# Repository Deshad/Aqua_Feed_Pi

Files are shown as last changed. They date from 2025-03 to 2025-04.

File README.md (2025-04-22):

# Aqua Matic  
# **Smart Aquarium Management System** 🐠
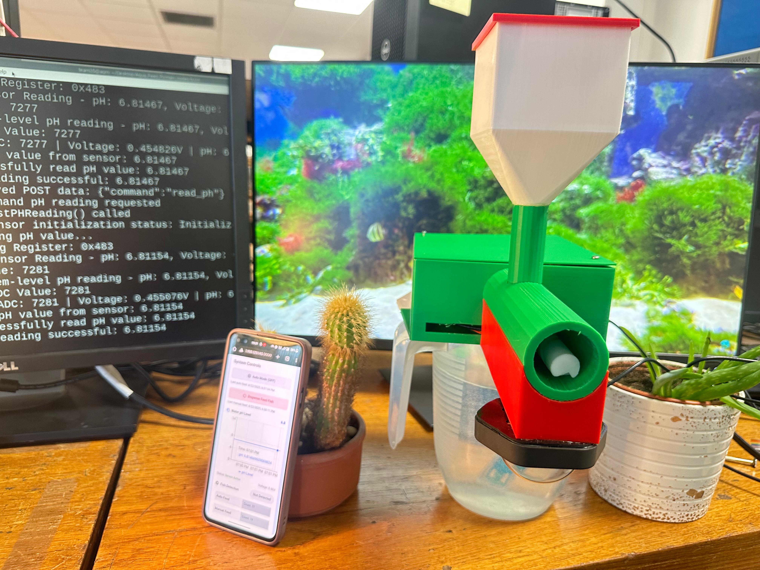
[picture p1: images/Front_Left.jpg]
 

## **📌 Project Overview**  
**Aqua Matic** is a smart, automated aquarium management system that uses a **PIR sensor and Pi-camera** to detect fish presence and regulate feeding schedules. 
For the people who love their goldies but can’t always be there—Aqua Feed Pi ensures your fish are fed, happy, and thriving, even when you're away! 🐠✨
Designed with Raspberry Pi, this project helps automate fish feeding efficiently, ensuring optimal care even when you're away.  

## **🚀 Features**  
✅ **Automated Feeding:** Dispenses food when fish are detected.  
✅ **PIR & Camera-based Detection:** Monitors fish activity for intelligent feeding.  
✅ **Remote Access:** Control and monitor the system via SSH or a web dashboard.

✅ **pH Monitoring:** Monitor pH value of the tank. 

✅ **Configurable Parameters:** Adjust feeding schedules and sensor sensitivity.  
✅ **Energy Efficient:** Optimized to reduce unnecessary food waste.  

---

## **🔧 System Components**  

- **Hardware:**  
  - Raspberry Pi  
  - PIR Motion Sensor  
  - Camera Module
  - pH Sensor    
  - DC Motor (for feeding mechanism)  
  - Power Supply  
  - Wi-Fi Module (optional, for remote access)
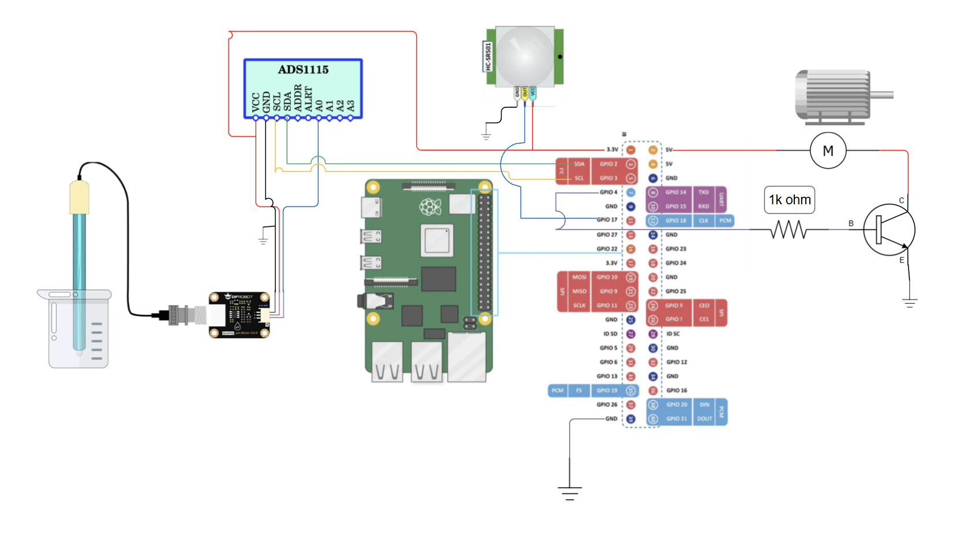
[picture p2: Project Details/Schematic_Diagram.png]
    

- **Software:**
  - OS (for Raspberry Pi system)
  - Cpp (for system control)  
  - OpenCV (for fish detection via camera)  
  - RPi.GPIO (for PIR and  motor control)  
  - Next.js (for web-based monitoring)  

---
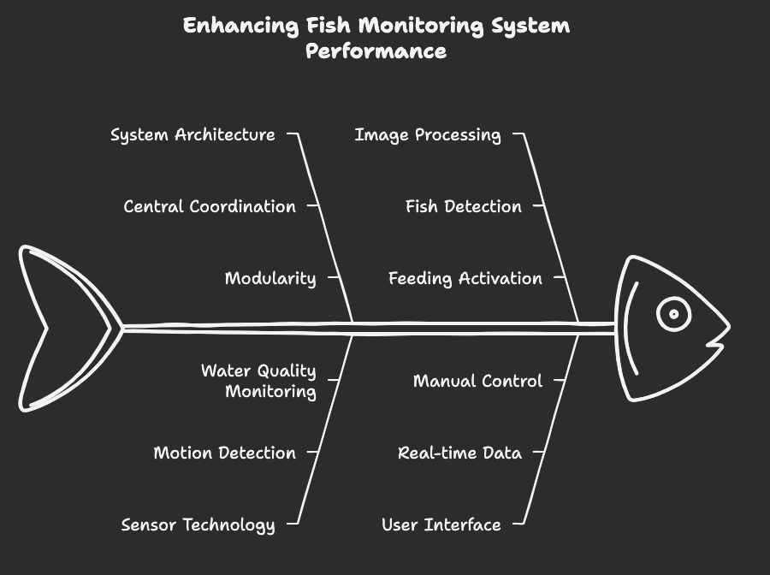
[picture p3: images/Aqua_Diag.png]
Aqua Matic Flow Chart
 

## **🛠 Installation & Setup**  

### **1️⃣ Clone the Repository**  
Make sure you have **Git** installed, then run:  

```bash
git clone https://github.com/Deshad/Aqua_Feed_Pi.git
cd Aqua_Feed_Pi

rm -rf build
mkdir build
cmake ..
make

```
Removing the build folder and make it again.

### **2️⃣ Install Dependencies**  
Install the following packages (on Debian-based systems):

```bash
sudo apt update
sudo apt install \
  libopencv-dev (>=4.5.0) \
  libjsoncpp-dev (>=1.9.4) \
  libgpiod-dev (>=1.6.0) \
  libi2c-dev \
  libcamera-dev \
  libcamera-tools
```
### **3️⃣ Setup Raspberry Pi Configuration**  

#### **Enable Camera**  

```bash
sudo raspi-config
```
- Navigate to *Interfacing Options* → *Enable Camera* → *Finish & Reboot*.  

#### **Enable PIR Sensor GPIO**  
Ensure you have connected the PIR sensor properly to the Raspberry Pi's GPIO pins.  

#### **Enable Motor GPIO**  
Ensure you have connected the transistor and motor properly to the Raspberry Pi's GPIO pins.  

#### **Enable I2C GPIO for PH Sensor**  
Ensure you have connected the ADC module (ADS1115) properly to the Raspberry Pi's GPIO pins 2 (SDA) & 3 (SCL).  
```bash
sudo raspi-config
```
- Navigate to *Interfacing Options* → *I2C* → *Yes* → *Finish & Reboot*.

(Install I2C Tools)
```bash
sudo apt install -y i2c-tools python3-smbus
```
---

## **🚀 Running the System**  

Execute the main script:  (file present in main_codes)

```bash
cd ~/Aqua_Feed_Pi/build
./fish_monitor
```
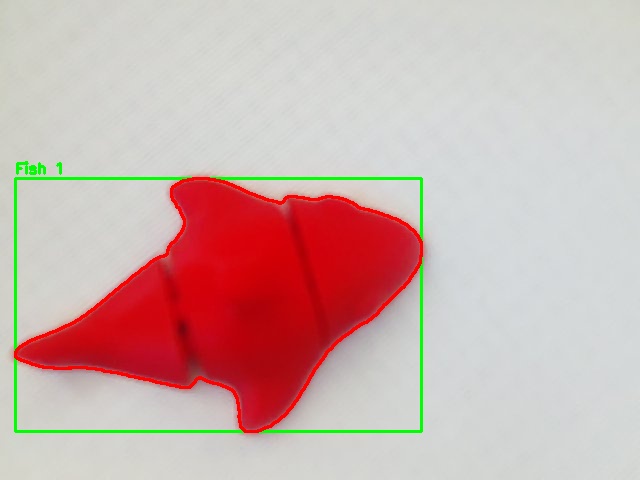
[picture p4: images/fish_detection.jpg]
 

---

## **🛠 Configuration**  

Modify `config.json` to adjust:  
- Feeding schedule  
- PIR sensor sensitivity  
- Camera threshold settings  

---

For web-based monitoring, run:  (file present in web folder)

```bash
npm run dev
```
Then, access the dashboard via your browser at `http://localhost:8000`.  

---

## **🐟 Troubleshooting**  

| Issue | Solution |
|---|---|
| Camera not detected | Run `vcgencmd get_camera` and check if `detected=1`. |
| PIR sensor not triggering | Check GPIO connections and ensure the correct pin mapping. |
| Motor not working | Ensure it’s connected properly and receiving the correct PWM signal. |
| PH Sensor incorrect measurement | Ensure the calibration of the PH level is correctly. |

---

## **🤝 Contributing**  

Contributions are welcome! If you’d like to improve the system, open an issue or submit a pull request.  

---

## **📜 License**  

This project is open-source under the MIT License.

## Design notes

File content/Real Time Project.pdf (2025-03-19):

AquaFeedPi

Objective:-
To predict when fish are hungry, you can monitor behavioral patterns or physiological changes. While it is challenging to determine when fish are hungry, they do not exhibit clear signs like other pets, such as dogs.
Usually, aquarium fish swim toward the surface because they associate the surface with food due to positive reinforcement, especially domesticated fish.

Theory:-
The lack of clear cues presents a challenging aspect of this project.
We can divide the indicators into two categories: Environmental and Behavioral.
1. Environmental Indicators:-Changes in water conditions can indirectly indicate hunger or feeding requirements.
a) pH Levels: (Possible)
The decomposition of uneaten food increases the alkalinity (pH) of water.
A sudden rise in pH may indicate that food is not being consumed, signaling potential hunger or overfeeding scenarios.
b) Dissolved Oxygen (DO) Levels: (Possible)
Well-fed fish are less active and consume less oxygen compared to hungry fish, which may exhibit increased swimming and oxygen consumption.
c) Nitrate/Nitrite Levels:(Sensor issue)
Low nitrate levels over time may imply that fish consume all provided food without leftovers, indicating efficient feeding and potential hunger at scheduled times.
2. Behavioral Patterns
Observing how fish behave under different feeding conditions can provide important insights:
a) Surface Activity:Hungry fish often swim near the water surface, eagerly waiting for food. Movement and Agitation:Increased erratic movements or gathering near feeding zones can indicate hunger.
b) Feeding Frenzy:A sudden rush to the feeding area when food is dropped may imply prior hunger.

Possible Solution:-
1.Infrared (IR) Motion Sensors:(Possible)
Detects increased activity near the feeding area (e.g., fish swimming near the surface). Example: HC-SR501 PIR Motion Sensor.
2.Underwater Cameras + Image Processing:
Use OpenCV or machine learning to analyze fish behavior (e.g., clustering near the feeder). 3.Water Quality Sensors:

Monitor parameters like dissolved oxygen or ammonia levels, which correlate with feeding activity.
Example: DFRobot Analog Dissolved Oxygen Sensor.
4.Ultrasonic Sensors:
Detect movement near the feeding zone (e.g., HC-SR04).
5.Load Cells:
Measure uneaten food to adjust feeding schedules (e.g., HX711 Load Cell). Usually used for dog feeder setups, so we have to see if it will be possible for fishes.

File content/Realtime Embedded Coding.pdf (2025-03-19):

# Realtime embedded coding in C++ under Linux

### Bernd Porr & Nick Bailey

### April 3, 2024

# Contents

1 Introduction | 3
2 Writing C++ device driver classes | 5
2.1 General recommendations on how to write your C++ classes for
2.2.2 | Adding directly an abstract method to the device driver
3 Threads | 19

1

### 4 Realtime/event processing within the Graphical User Interface

Qt | 24
5 Realtime web server/client communication | 28
6 Setters | 34
A License | 36

2

# Chapter 1

# Introduction

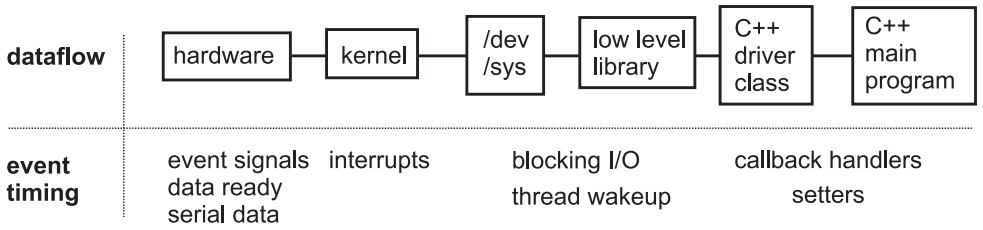
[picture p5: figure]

Figure 1.1: Dataflow and timing in low level realtime coding

## 1.1 Event based coding in the Linux userspace

Realtime embedded coding is all about events. These can be a binary signal such as somebody opening a door or an ADC signalling that a sample is ready to be picked up. Fig. 1.1 shows the basic dataflow and how event timing is established: devices by themselves have event signals such as “data ready” or “crash sensor has been triggered”. The Linux kernel receives these as interrupt callbacks. However, userspace has no direct interrupt mechanism; instead it has blocking I/O where a read or write operation blocks until a kernel-side interrupt has happened. A blocking I/O call returning may then be translated callbacks between classes by waking up threads. Data is transmitted back to the hardware via methods called “setters”, which change an object’s attributes and potentially do other processing.

3

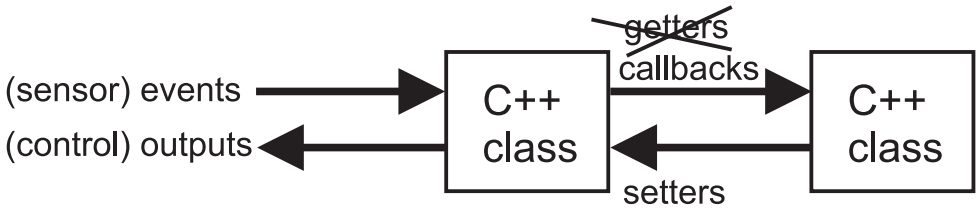
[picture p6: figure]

Figure 1.2: A realtime system with two C++ classes. Communication between classes is achieved with callbacks (not getters) for incoming events and setters to send out control events. The control output itself receives its timing from the events so that the loop is traversed as quickly as possible.

Fig. 1.2 shows the overall communication between C++ classes in a realtime system. This communication is done via callbacks (not getters) and setters, where an event from a sensor traverses according to its realtime requirements through the C++ classes via callbacks and then back to the control output via setters. For example, a collision sensor at a robot triggers a GPIO pin, which then triggers a callback to issue an avoidance action which in turn then sets the motors in reverse.
Callbacks can be seen as userspace interrupt service routines. These must always complete immediately so that the caller is not experience any noticeable delay. For example when a user presses a button in a GUI the callback must be processed without any noticeable delay which is application specific. If processing takes longer then a thread should be started which in turn then will then have a callback signalling success.
In the following sections we are describing how to write event driven code in C++. Important here is the interplay between blocking I/O and threads: chapter 2 focuses on how to wrap the low level blocking Linux I/O in a class and how to establish the communication between classes while the chapter 3 describes how threads can effectively be used to trigger callbacks with blocking I/O. Chapter 4 then presents the event based communication in Qt, in particular user interaction and animations. Chapter 5 tackles the same issues as for Qt but for website server communication. The final chapter 6 then describes how events are transmitted back from a C++ class to the user with the help of setters.

4

# Chapter 2

# Writing C++ device driver classes

This chapter focuses on writing your own C++ device driver class hiding away the complexity (and messy) low level C APIs and/or raw device access. How are events translated into I/O operations? On the hardware-side we have event signals such as data-ready signals or by the timing of a serial or audio interface. The Linux kernel translates this timing info into blocking I/O on the pseudo filesystem /dev which means that a read operation blocks until data has arrived or an event has happened. The task of a C++ programmer is to hide this complexity and these quite different approaches in C++ classes which communicate via callbacks and setters with the client classes. The rest of the program will then appear simple and be easy to maintain.

## 2.1 General recommendations on how to write your C++ classes for devices

As said above the main purpose of object oriented coding here is to hide away the complexity of low level driver access and offer the client a simple and safe way of connecting to the sensor. In particular:

1. Setters and callbacks hand over physical units (temperature, acceleration, . . . ) or relative units but not raw integer values with no meaning.
2. The sensor is configured by specifying physical units (time, voltage, temperature) and not sensor registers. Default config parameters should be specified that the class can be used straight away with default parameters.

5

3. The class comes with simple demo programs demonstrating how a client program might use it.

## 2.2 Callbacks in C++ device classes

As said in the introduction your hardware device class has callback interfaces to hand back the data to the client.
There are different ways of tackling the issue of callbacks but the simplest one is defining a method as abstract and asking the client to implement it in a derived class. That abstract function can either be in a separate interface class or part of the device class itself. So, we have two options:
1. The callback is part of the device driver class:

class MyDriver {
void start(DevSettings settings = DevSettings() ); void stop();
virtual void callback(float sample) = 0;
};
2. The callback is part of an interface class:

class CallbackInterface {
virtual void callback(float sample) = 0; };

and then registering it in the main device driver class:

class MyDriver {
void registerCallback(CallbackInterface* cb); };

These two options are now explained in greater detail.

6

### 2.2.1 Creating a callback interface

Here, we create a separate interface class containing a callback as an abstract method:

class LSM9DS1callback {
public:
virtual void hasSample(LSM9DS1Sample sample) = 0;
};

The client then implements the abstract method hasSample(), instantiates the interface class and then saves its pointer in the device class, here called lsm9ds1Callback.

void LSM9DS1::dataReady() {
LSM9DS1Sample sample;
// fills the sample struct with data // ...
lsm9ds1Callback->hasSample(sample); }

The pointer to the interface instance is transmitted via a setter which receives the pointer of the interface as an argument, for example:

void LSM9DS1::registerCallback(LSM9DS1callback* cb);

This allows to register a callback optionally. The client may or may not need one. See https://github.com/berndporr/rpi_AD7705_daq for a complete example.

### 2.2.2 Adding directly an abstract method to the device driver class

Instead of creating a separate class containing the callback you can also add the callback straight to the device driver class.

class ADS1115rpi {
virtual void hasSample(float sample) = 0; ...
};

7

This forces the client to implement the callback to be able to use the class. This creates a very safe environment as all dependencies are set at compile time and the abstract nature of the base class makes clear what needs to be implemented. See https://github.com/berndporr/rpi_ads1115 for a complete example.

### 2.2.3 Callback arguments

Above the callbacks just delivered one floating point value. However, often more than one sample or more complex data are transmitted:

- Complex data: do not put loads of arguments into the callback but define a struct. For example an ADC might deliver all 4 channels at once:

class ADmulti {

struct ADCSample {
float ch1;
float ch2;
float ch3;
float ch4;
};
virtual void hasSample(ADCSample sample) = 0; ...
};

Depending on your application, you might consider the values not useful individually and therefore prefer a std::tuple.

- Arrays: Use arrays which contain the length of the arrays: either std::array, std::vector, etc or const arrays and then references to these so that the callback knows the length. For example the LIDAR callback uses a reference to a const length array:

/**
* Callback interface which needs to be implemented by the user. **/
struct DataInterface {

8

virtual void newScanAvail( float rpm,
A1LidarData (&)[A1Lidar::nDistance]) = 0; };

Here A1Lidar::nDistance is a constant-expression giving the fixed array length, and (&)[A1Lidar::nDistance] a reference to a constant-length array which containing A1LidarData stucts. If you’re going to use types that hard to key-in often, typedef them.

In terms of memory management:

1. Low sampling rate complex data structures: allocate as a local variable. It
can be a simple type or a struct. See dataReady() in: https://github.com/berndporr/LSM9DS1_RaspberryPi_CPP_Library/blob/master/LSM9DS1. cpp. (https://github.com/berndporr/LSM9DS1_RaspberryPi_CPP_Library/blob/master/LSM9DS1.cpp)
2. High sampling rate buffers: allocate memory on the heap in the constructor
or in the private section of the class as a const length array and pass on a reference. See getData() in https://github.com/berndporr/rplidar_rpi. (https://github.com/berndporr/rplidar_rpi)

## 2.3 Low level userspace device access

The following sections provide pointers of how to write the C++ driver classes for different hardware protocols.
To emulate an “interrupt” or event in userspace we need blocking I/O which provides the timing for example when waiting for a GPIO change, doing audio or video I/O.
Generally any userspace program talks to the kernel via pseudo files in the /dev or /sys directories.

### 2.3.1 Video camera capture (openCV)

Ubuntu / Debian Linux systems

Reading from a video camera is usually done with the help of openCV which in turn then talks to the low level C API which in turn talks to the kernel via /dev/video*.

9

while(running) {
cv::Mat cap;
videoCapture.read(cap);
sceneCallback->nextScene(cap);
}

The read(cap) command is blocking till a new frame has arrived which is then transmitted with the callback nextScene to the client. The full code of the example camera class is here: https://github.com/berndporr/opencv-camera-callback.

Raspberry PI

On the raspberry PI a new video stack has been implemented which talks to the kernel via /dev/media*. This is incompatible with openCV and the code in section 2.3.1 won’t work. The good news is that libcamera already implements a callback interface so a loop is no longer needed. Instead, one just needs to
register a callback to receive the video frames. The bad news is that libcamera
is highly complex and requires a lot of additional code (https://github.com/libcamera-org/libcamera/blob/master/Documentation/guides/application-developer. rst). (https://github.com/libcamera-org/libcamera/blob/master/Documentation/guides/application-developer.rst) To make life easier we have written a C++ wrapper around the libcamera
C++ API which exposes a callback which delivers image frames in openCV format to mimick the behaviour of the openCV code of the previous section 2.3.1: https://github.com/berndporr/libcamera2opencv.

### 2.3.2 Audio (ALSA)

The standard framework for audio is alsa: https://github.com/alsa-project. ALSA is packet based with a read command returning a chunk (”buffer”) of audio and write emitting one. There are calls to set the sample format, sample rate, buffer size and so forth.
First, the parameters are requested and the driver can modify or reject them:

/* Signed 16-bit little-endian format */ snd_pcm_hw_params_set_format(handle, params, SND_PCM_FORMAT_S16_LE);

/* One channel (mono) */
snd_pcm_hw_params_set_channels(handle, params, 1);

10

/* 44100 bits/second sampling rate (CD quality) */ val = 44100;
snd_pcm_hw_params_set_rate_near(handle, params,
&val, &dir);

Then playing sound is done in an endless loop were a read() or write() command is issued. Both are blocking so that they guarantee event timing of audio both way.

while (running) {
if ((err = snd_pcm_readi (handle, buffer, buffer_frames)) != buffer_frames) { if (errCallback) errCallback->hasError();
}
if (sampleCallback) sampleCallback->hasData(buffer);
}

For a full coding example “aplay” and “arecord” are a good start. Both can be found here: https://github.com/alsa-project.

### 2.3.3 Bluetooth

Bluetooth has also blocking I/O so that one can wait for incoming packets on a socket:

void run() {
doRun = 1;
while (doRun) {
recv(btsocket, recvbuffer, sizeof(recvbuffer), 0); hasData(recvbuffer);
}
};

Here the recv command blocks until new data has arrived.

### 2.3.4 General purpose I/O (GPIO)

GPIO pins are not just simple digital ports but they can be used to turn non-blocking I/O into blocking I/O, or in other words: events!

11

libgpiod

The GPIO (of the raspberry PI) can easily be controlled via the /dev filesystem and libgpiod.
Use the commandline tool gpioinfo to print a list of all available GPIO pins. When you use the gpiod library you:
1. first choose the GPIO chip you want to use. Raspberry PIs 1-4 have only one chip. The Raspberry PI 5 has 4 chips. Selection can be made either by number, name or pseudo-file:

struct gpiod_chip *chip =
gpiod_chip_open_by_name("gpiochip0");

and then,

2. select a pin on the chip:

struct gpiod_line *pinRed = gpiod_chip_get_line(chip, 24);

Output

Once you have a pointer to the pin you can then set its direction, for example as an output pin, with:

gpiod_line_request_output(pinRed, "example1", 0);

and set its value with:

gpiod_line_set_value(pinRed, 1);

Events

Blocking I/O is very good for event processing. Calling a blocking I/O function causes the thread to wait efficiently, then when the I/O call returns, the thread will wake up. This means that a change in level from low to high or high to low unblocks an I/O operation, awakening its underlying thread which then performs a callback.
To request event processing on a pin simply requires this single command:

12

int ret =
gpiod_line_request_rising_edge_events(pinSwitch, "Consumer1");

This will turn the GPIO pin pinSwitch into an input pin and enable blocking I/O on this pin.
Then start a thread where its worker contains:

void worker() {
while (running) {
constexpr struct timespec ts = { 1, 0 }; gpiod_line_event_wait(pinSwitch, &ts); struct gpiod_line_event event; gpiod_line_event_read(pinSwitch, &event); event_callback();
}
}

The gpiod line event wait waits for a rising edge at the GPIO pin, or for 1 second (+ 0 ns), whichever is longer, and then unblocks. The return value is 1 if a GPIO event occurred, 0 if timeout interval was exceeded, and -1 in the event of an error. In production code, you’d need to check this return value. Then gpiod line event read transfers the kernel event to userspace and clears it out of the kernel event queue. It’s important to do the read operation even if the event-struct is never used. The callback is made, and the loop repeats until another thread requrests termination by setting running to false. See https://github.com/berndporr/rpi_ads1115 for a complete example.

Releasing the GPIO

Once you are finished, release the GPIO pin with:

gpiod_line_release(pinRed);

and close the chip:

gpiod_chip_close(chip);

13

Table 2.1: SPI modes

SPI Mode | CPOL | CPHA | Idle state
0 | 0 | 0 | L
1 | 0 | 1 | L
2 | 1 | 1 | H
3 | 1 | 0 | H

### 2.3.5 SPI

SPI is a protocol which usually transmits and receives at the same time. Its calls are blocking for the duration of receive and transmit but cannot be used for event based processing. If an SPI device is used events should be transmitted via an additional GPIO line. Even though data might not be used it needs to be matched up, because the same clock is used to send and collect the data signal (it is isochronous). So if you send 8 bytes the hardware receives 8 bytes at the same time.
Transfer to/from SPI is best managed by the low level access to /dev. Open the SPI device with the standard open() function:

int fd = open( "/dev/spidev0.0", O_RDWR);

Then set the SPI mode (see table 2.1):

int ret = ioctl(fd, SPI_IOC_WR_MODE, &mode);

as explained, for example, here: https://www.analog.com/en/analog-dialogue/articles/introduction-to-spi-interface.html. (https://www.analog.com/en/analog-dialogue/articles/introduction-to-spi-interface.html)
Because SPI is isochronous, read() and write() can’t be used to transmit and receive data. Instead, the simultaneous read and write is performed using
an ioctl() to do the communication. Populate this struct:

struct spi_ioc_transfer tr {
.tx_buf = (unsigned long)tx1,
.rx_buf = (unsigned long)rx1, .len = ARRAY_SIZE(tx1),
.delay_usecs = delay,
.speed_hz = speed,
.bits_per_word = 8,
};

14 which points to two character buffers “tx” and “rx” with the same length¹
Reading and simultaneous writing then happens via this ioctrl() function call:

int ret = ioctl(fd, SPI_IOC_MESSAGE(1), &tr);

Sometimes the SPI protocol of a chip is so odd that even the raw I/O via /dev won’t work and you need to write your own bit banging interface, for example done here for the ADC on the alphabot: https://github.com/berndporr/alphabot/blob/main/alphabot.cpp#L58. (https://github.com/berndporr/alphabot/blob/main/alphabot.cpp#L58) This is obviously far from ideal as it might require usleep() commands so that acquisition needs to be run in a separate thread (the alphabot indeed uses a timer callback in a separate thread). Overall the SPI protocol is often device dependent and calls for experimentation to get it to work. On some ADCs the SPI clock is also the conversion clock and a longer lasting clock signal sequence is required, making it necessary to transmit dummy bytes in addition to the payload.
As a general recommendation do not use SAR converters which use the SPI data clock also as acquisition clock as they are often not compatible with the standard SPI transfers via /dev. Use sensors or ADCs which have their own clock signal.

### 2.3.6 I2C

I2C is a protocol which either receives or transmits. Its calls are blocking for the duration of receive or transmit but only in rare cases can be used for event based processing. It is recommended to use an additonal GPIO pin for events for example for a data-ready event.
The I2C bus has two signal lines (SDA & SDL) which must be pulled up by resistors. Every I2C device has an address on the bus. You can scan a bus with i2cdetect (part of the i2c-tools package):

root@raspberrypi:/home/pi# i2cdetect -y 1
0 | 1 | 2 | 3 | 4 | 5 | 6 | 7 | 8 | 9 | a | b | c | d | e | f
00: | -- -- -- -- -- -- -- --
10: -- -- -- -- -- -- -- -- -- -- -- -- -- -- 1e --
20: -- -- -- -- -- -- -- -- -- -- -- -- -- -- -- --

1This code fragment’s use of designated initialisers officially requires C++2a, although most C++ compilers support it when compiling with older standards. In C it’s been fine for a while!

| | | | | | | | | 15

30: -- -- -- -- -- -- -- -- -- -- -- -- -- -- -- --40: -- -- -- -- -- -- -- -- -- -- -- -- -- -- -- --50: -- -- -- -- -- -- -- -- 58 -- -- -- -- -- -- --60: -- -- -- -- -- -- -- -- -- -- -- 6b -- -- -- --70: -- -- -- -- -- -- -- --
root@raspberrypi:/home/pi#

In this case there are 3 I2C devices on the I2C bus at addresses 1E, 58 and 6B and need to be specified when accessing the I2C device.

Raw /dev/i2c access

I2C either transmits or receives but never at the same time so here we can use the standard C read/write commands. However, we need to use ioctrl to tell the kernel the I2C address:

char buf[2];
int file = open("/dev/i2c-2",O_RDWR); int addr = 0x58;
ioctl(file, I2C_SLAVE, addr); write(file, buf, 1)
read(file, buf, 2)

where addr is the I2C address. Then use standard read() or write() commands. Usually the 1st write operation tells the chip which register to read or write to. Subsequent operations read or write that register. For example, reading a 16 bit register:

unsigned 2c_readWord(uint8_t reg)
{
uint8_t tmp[2];
tmp[0] = reg;
write(fd_i2c,&tmp,1);
read(fd_i2c, tmp, 2);
return (((unsigned)(tmp[0])) << 8) | ((unsigned)(tmp[1]));
}

Similarly writing a 16 bit register writes 3 bytes to the I2C bus (register and the 16 bit data):

16 void i2c_writeWord(uint8_t reg, unsigned data) {
uint8_t tmp[3];
tmp[0] = reg;
tmp[1] = (char)((data & 0xff00) >> 8); tmp[2] = (char)(data & 0x00ff); write(fd_i2c,&tmp,3);
}

### 2.3.7 Access to hardware via special devices in /sys

Some sensors are directly available via the sys filesystem in human readable format. For example

cat /sys/class/thermal/thermal_zone0/temp

gives you the temperature of the CPU.

### 2.3.8 Accessing physical memory locations (danger!)

Don’t. In case you really need to access registers you can also access memory directly. This should only be used as a last resort. For example, setting the clock for the AD converter requires turning a GPIO pin into a clock output pin. This is not yet supported by the drivers so we need to program registers on the RPI.

- Linux uses virtual addresses so that a pointer won’t point to a physical memory location. It points to three page tables with an offset.
- Special device /dev/mem allows access to physical memory.
- The command mmap provides a pointer to a physical address by opening /dev/mem.
- Example:

int *addr;
if ((fd = open("/dev/mem", O_RDWR|O_SYNC)) < 0 ) { printf("Error opening file. \n");
close(fd);
return (-1);

17

}
addr = (int *)mmap(0, num*STRUCT_PAGE_SIZE, PROT_READ, MAP_PRIVATE, fd, 0x0000620000000000);
printf("addr: %p \n",addr);
printf("addr: %d \n",*addr);
- Use this with care! It’s dangerous if not used properly.

## 2.4 Kernel driver programming

You can also create your own /dev/mydevice in the /dev filesystem by writing a kernel driver and a matching userspace library. For example the USB mouse has a driver in kernel space and translates the raw data from the mouse into coordinates. However, this is beyond the scope of this handout. If you want to embark on this adventure then the best approach is to find a kernel driver which does approximately what you want and modify it for your purposes.

## 2.5 Conclusion

The communication between C++ classes is achieved via callbacks and setters. The event from the sensor traverses the C++ classes via callbacks and then back to the control output via setters.
From the sections above it’s clear that Linux user-space low level device access is complex, even without taking into account the complexity of contemporary chips which have often a multitude of registers and pages of documentation. Your task is to hide away all this (scary) complexity in a C++ class and offer the client an easy-to-understand interface.

18

# Chapter 3

# Threads

## 3.1 Introduction

In realtime systems threads have two distinct functions:

1. Endless loops with blocking I/O or GPIO wakeups to establish precise timing for callbacks.
2. Asynchronous execution of time-consuming tasks with a callback after the task has completed.

## 3.2 Processes and Threads

Processes are different programs which seem to be running at the same time. A small embedded system may only have a single CPU core, so this this is achieved by the operating system switching approximately every 10ms from one process to the next so it feels as if they are running concurrently. A thread is a lightweight process. A process may have multiple threads which share the same addressspace and are all started from within the parent process. As with processes, the threads seem to be running at the same time. When a thread is started it runs simultaneously with the main process which created it.

19

## 3.3 Thread and worker

A thread is just a wrapper for the actual method which is running independently. The method being run in the thread is often called a worker.

### 3.3.1 Creating threads

In C++ a worker is a method within a class:

uthread = new std::thread(&MyClassWithAThread::run, this);

where MyClassWithAThread is a class containing the function “run”:

class MyClassWithAThread {
void run() {
// ... hard work is done here doCallback(result); // hand the result over }
}

Note that the & signifies a functor, a method prototype. Instead of using functors you can also use a lambda function to call a method in the instance:

uthread = std::thread([this](){run();});

### 3.3.2 Lifetime of a thread

Threads terminate simply once the worker has finished its job. To tell the client that a thread has finished you can use a callback to trigger an event. Sometimes it’s important to wait for the termination of the thread, for example when your whole program is terminating or when you stop an endless loop in a thread. To wait for the termination of the thread use the “join()” method:

void stop() {
uthread->join();
delete uthread;
}

It’s also important is also to release the memory of a thread after it has finished to avoid memory leaks, hence the delete command.

20

### 3.3.3 Running/stopping workers with endless loops

Threads with endless loops are often used in conjunction with blocking I/O which provide the timing:

void run() {
running = true;
while (running) {
read(buffer); // blocking
doCallback(buffer); // hand data to client }
}

Note the flag running which is controlled by the main program and is set to zero to terminate the thread:

void stop() {
running = false; // <----- HERE!! uthread->join();
delete uthread;
}

Note that join() is a blocking operation and needs to be used with care not to lock up the main program. You probably only need it when your program is terminating. See https://github.com/berndporr/rpi_AD7705_daq for an example.
If your program creates and joins several threads while executing, with care you might be able to design your program to allow an end-of-life thread to carry on tidying up in the background after you stop it by setting running = false;. In this case only need execute join() to be sure that the thread has finished. Joining a terminated thread is OK (the call just returns immediately) but you absolutely must not join a thread more than once, nor delete a thread until you’ve joined it.

### 3.3.4 Timing within threads

Threads are perfect to create timing without using sleep commands with the help of blocking I/O. Blocking I/O puts a thread to sleep and is woken up after new data has arrived or has been written to a device. Blocking I/O won’t consume any CPU power and is perfect to tell the kernel that it can execute other threads in the meantime.

21

Timing with blocking I/O

Blocking I/O (read, write, etc) is by far the best approach to time the data coming in because the thread goes to sleep when it’s waiting for I/O but wakes up very quickly after new data has arrived.
In this example the blocking read command creates the timing of the callback:

void run() {
running = 1;
while (running) {
read(buffer); // blocking
doCallback(buffer); // hand data to client }
}

If the I/O is non-blocking or if you are making blocking I/O non-blocking with:

int flags = fcntl(fd, F_GETFL, 0);
fcntl(fd, F_SETFL, flags | O_NONBLOCK);

you can then use select() to wait for data:

FD_ZERO(&rdset);
FD_SET(fd,&rdset);
struct timeval timeout;
timeout.tv_sec = 0;
timeout.tv_usec = 500000;
int ret = select(fd+1,&rdset,NULL,NULL,&timeout); if (ret < 0) return ret;
// non-blocking I/O read
ret = read(fd,buffer,bytes_per_sample * n_chan);

which has the advantage that it has a timeout so that you can create both error and data callbacks. Even if the I/O is blocking using select or poll has the advantage that these commands have timeouts while the read and write commands would block forever. This is also the recommended approach for libgpiod where the gpiod line event wait is not needed because gpiod line event read is blocking but would block indefinitely.

22

## 3.4 Timing with Linux timers

If no timing info from the sensor is available one can use a timer as a last resort. Under Linux reliable timing can be again created with the help of blocking I/O and threads. Here, a special file descriptor receives information when a timer has fired first and at which intervals after:

fd = timerfd_create(CLOCK_MONOTONIC, 0);
its.it_value.tv_sec = millisecs / 1000; its.it_value.tv_nsec = (millisecs % 1000) * 1000000; its.it_interval.tv_sec = millisecs / 1000; its.it_interval.tv_nsec = (millisecs % 1000) * 1000000; if (timerfd_settime(fd, 0, &its, NULL) == -1)
throw("Could not start timer");

This file descriptor is then used in a loop with a blocking read command which then wakes up at the specified intervals:

running = true;
while (running) {
uint64_t exp;
read(fd, &exp, sizeof(uint64_t)); timerEvent();
}

where timerEvent is as usual the callback which is called at the specified intervals.
However, generally it’s not recommended to use timers for anything which needs to be sampled at high temporal precision, for example ADC converters or sensors with sampling rates higher than a few Hz.

## 3.5 Conclusion

Threads play a central role in real-time coding as, together with blocking I/O, they establish the callback interfaces. Every event handler runs in a separate thread.
Callbacks are also used to signal the termination of threads, which shows again the close relationship between threads and callbacks.

23

# Chapter 4

# Realtime/event processing within the Graphical User Interface Qt

## 4.1 Introduction

Qt is a cross-platform windows development environment for Linux, Windows and Mac. Such graphical user interfaces have realtime requirements because, for example, pressing a button should trigger an instant response by the application so that the user thinks this has been instantaneous. QT also works with callbacks as introduced above but they are wrapped in a QT-specific signal/slot concept. Elements in Qt are Widgets which can contain anything form plots, buttons or text fields. They are classes. You can define your own widgets or use readymade ones. Realtime communication within QT happens between widgets where then one widget calls another widget, for example a button the calls the main window if a button press has happened.
The arrangements of widgets on the screen is managed by layouts. There are different ways of declaring layout in Qt. One is using a markup language which then has matching classes; another is creating to use only C++ classes. We show how to organise the layout using the second method. This avoids having the learn an additional language and is consistent with the general trend to use code to declare the layout in this and other frameworks (SwiftUI, for example). This is an example how widgets are organised into nested vertical and horizontal layouts (see Fig. 4.1 for the result).

// create 3 widgets
button = new QPushButton;

24

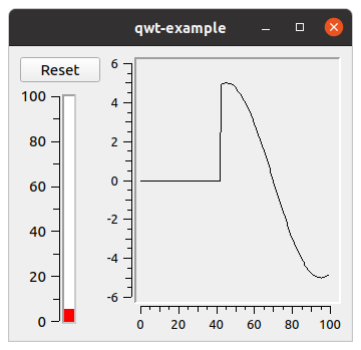
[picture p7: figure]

Figure 4.1: QT example layout

thermo = new QwtThermo;
plot = new QwtPlot;

// vertical layout
vLayout = new QVBoxLayout; vLayout->addWidget(button); vLayout->addWidget(thermo);

// horizontal layout
hLayout = new QHBoxLayout; hLayout->addLayout(vLayout); hLayout->addWidget(plot);

// main layout
setLayout(hLayout);

25

## 4.2 Callbacks in Qt

### 4.2.1 Events from widgets

In contrast to our low level callback mechanism using interfaces, Qt rather directly calls methods in classes. The problem is that function pointers cannot be directly used as a class has instance pointers to its local data. So a method of a class needs to be combined with the instance pointer. The Qt method “connect” does exactly that:

connect(button, &QPushButton::clicked,
this, &Window::reset);

The QPushButton instance button has a method called clicked() which is called whenever the user clicks on the button. This is then forwarded to the method reset() in the application Widget.

### 4.2.2 Plotting realtime data arriving via a callback

The general idea is to store the real-time samples from a callback in a buffer and trigger a screen refresh at a lower rate. For example, we may choose to replot the samples in the buffer every 40 ms because that fast enough for the user, whereas plotting the whole buffer every sample would be too CPU-intensive.
A callback addSample() is called in real-time whenever a sample has arrived:

void Window::addSample( float v ) {
// add the new input to the plot
std::move( yData, yData + plotDataSize - 1, yData+1 ); yData[0] = v;
}

which stores the sample v in the shift buffer yData.
Then the screen refresh (which is slow) is done at a lower and unreliable rate:

void Window::timerEvent( QTimerEvent * )
{
curve->setSamples(xData, yData, plotDataSize); plot->replot();
thermo->setValue( yData[0] );
update();
}

26 update() in the timer event-handler generates a paint event and Qt then invokes the repaint handler “as soon as possible” (which is to say, not in realtime) to repaint the canvas of the widget:

void ScopeWindow::paintEvent(QPaintEvent *) {
QPainter paint( this );

paint.drawLine( ... )
}

Note that neither the timer nor the update() function is called in a reliable way but whenever Qt chooses to do it. So Qt timers cannot be used to sample data but should only be used for screen refresh and other non-time-critical reasons.

## 4.3 Conclusion

Events in Qt are generated by user interaction, for example a button press or moving the mouse. As before Qt provides a callback mechanism via the connect() method. Callbacks from Qt timers may be used for animations but must not be used for real-time events as Qt timers won’t guarantee a reliable timing.

27

# Chapter 5

# Realtime web server/client communication

## 5.1 Introduction

There is a wide diversity of Web server / client applications ranging from shopping baskets on vendor sites to social media.
Generally it’s easy to create dynamic content (see PHP or nodejs) and this is well documented. However, feeding realtime data from C++ to a web page or realtime button presses back to C++ is a bit more difficult.
It’s important to recognise where events are generated: it is always the client (web browser or mobile app) which triggers an event, be it sending data over to the server or requesting data. It’s always initiated by the client.

## 5.2 REST

The interface between a web client (browser or phone app) is usually implemented as a Representational State Transfer Architectural (REST) API by communicating via an URL on a web server. The requirements for this API are very general and won’t define the actual data format:

Uniform interface. Any device connecting to the URL should get the same reply. No matter if a web page or mobile phone requests the temperature of a sensor the returned format must always be the same.

28

Client-server decoupling. The only information the client needs to know is the URL of the server to request data or send data.

Statelessness. Each request needs to include all the information necessary and must not depend on previous requests. For example a request to a buffer must not alter the buffer but just read from it so that another user reading the buffer shortly after receives the same data.

See https://www.ibm.com/cloud/learn/rest-apis for the complete list of REST design principles.

## 5.3 Data format: JSON

The most popular dataformat is JSON (application/json) which is basically a map of (nestable) key/value pairs:

{
temperature: [20, 21, 20, 19, 17], steps: 100,
comment: "all good!"
}

Since JSON is human-readable text a web server can simply generate that text send it over via http or https. There is no difference except that the MIME format is 'application/json' instead of html.

## 5.4 Server

On the Linux system a web server needs to be set up. There are a variety of different options available but we are focusing here on the ones which can be used for C++ communication (i.e. CGI).

### 5.4.1 Web servers (http/https)

- NGINX: Easy to configure but very flexible web server. Pronounced “Engine-X”.
- Apache: Hard to configure but safe option

29

- lighttpd: Smaller web server with a small memory footprint. Pronounced “lighty”.

Note that it’s possible to run different web servers at the same time where they then act as proxies for a central web server visible to the outside world. In particular nginx makes it very easy to achieve this.

Figure 5.1: FastCGI dataflow.

### 5.4.2 FastCGI

FastCGI (see Fig 5.1) is written in C++ and generates the entire content of the http/https request. In particular here we generate JSON packets which can then be processed by client JavaScripts and vice versa. For realtime applications JSON transmission is perfect because the client-side JavaScript can request and receive JSON packages
A fast CGI program is a UNIX commandline program which communicates with the web server (nginx, Apache, . . . ) via a UNIX socket which in turn is a pseudo file located in a temporary directory for example /tmp/sensorsocket. The web server then maps certain http/https requests to this socket. An example configuration for nginx looks like this:

location /sensor/ {
include | fastcgi_params;
fastcgi_pass | unix:/tmp/sensorsocket;
}

If the user does a request via the URL www.mywebpage.com/sensor/ then nginx contacts the fastcgi program via this socket. The fastcgi program then needs to return the content. Internally this will be a C++ callback inside of the fastcgi program.

30

The C++ fastcgi API https://github.com/berndporr/fastcgi_json_cpp_api (https://github.com/berndporr/fastcgi_json_cpp_api) is wrapper around the quite cryptic fastcgi C library and we discuss its callback handlers now.

### 5.4.3 Server → client

The fastCGI callback expects a JSON string (application/json) with the data transmitted form the server to the client. Use the jsoncpp library (standard debian/Ubuntu package) to create JSON.

class JSONcallback : public JSONCGIHandler::GETCallback { public:
/**
* Gets the data and sends it to the webserver.
* The callback creates two JSON entries. One with the * timestamp and an array of sensor readings.
**/
virtual std::string getJSONString() {
Json::Value root;
root["epoch"] = (long)time(NULL);
Json::Value values;
for(int i = 0; i < datasink->values.size(); i++) { values[i] = datasink->values[i];
}
root["values"] = values;
Json::StreamWriterBuilder builder;
const std::string json_file = Json::writeString(builder, root); return json_file;
};

### 5.4.4 Client → server: POST

Like in any GUI the client can press a button and create an event. Here, the server then receives the JSON data as a callback called “postArg”:

virtual void postString(std::string postArg) {
const auto rawJsonLength = static_cast<int>(postArg.length()); JSONCPP_STRING err;

31

Json::Value root;
Json::CharReaderBuilder builder;
const std::unique_ptr<Json::CharReader> reader(builder.newCharReader()); reader->parse(postArg.c_str(), postArg.c_str() + rawJsonLength, &root, &err) // do something with root
}

where root is a std::map.

## 5.5 Client code: javascript for websites

Generally on the client side (= web page), HTML with embedded JavaScript is used to generate realtime output/input without reloading the page. JavaScript is event driven and has callbacks so it’s perfect for realtime applications. Use jQuery to request and post JSON from/to the server.
For example here we request data from the server as a JSON packet every second:

// callback when the JSON data has arrived
function getterCallback(result) {
var temperatureArray = result.temperatures; // plot the array here
}

// timer callback (same idea as in Qt to define a refresh rate) function getTemperature() {
// get the JSON data
$.getJSON("/data/:80",getterCallback);
}

// document ready callback
function documentReady() {
// request new data from the server every second window.intervalId = setInterval(getTemperature , 1000); }

// called when the web page has been loaded $(document).ready( documentReady );

32

Mobile phone programming in JAVA, Kotlin or Swift is also purely callback driven as the JS code above and differs only in its syntax.

## 5.6 Conclusion

Events in web based communication are always triggered by the web browser or the mobile app in exactly the same way as Qt does it, for example by a button press. The same applies for animations where a client-side timer requests data from the server. Thus, these client side events either cause transmission of data from the web browser to the web server or request data from the web server. Nowadays the protocol is always http or https and a RESTful interface with JSON being the most popular data format.

33

# Chapter 6

# Setters

In Fig. 1.2 we have seen that data flows from the sensors to the C++ classes via callbacks then returns from the inner C++ classes to motor or display outputs is via setters. Setters are also used for setting configuration parameters.
A setter is a simple method in a class, for example to set the speed of a motor:

class Motor {
/**
* Set the Left Wheel Speed
* @param speed between -1 and +1 **/
void setLeftWheelSpeed(float speed);
};

Again as with callbacks it’s important to abstract away from the hardware, for example normalising the speed of the motor between −1 and +1 and hiding away the complexity of the PWM or GPIO ports in the class.
If a setter has more than one argument, in particular for configuration, it’s highly recommended to use a struct to set the values. For example setting the parameters of the ADS1115:

/**
* ADS1115 initial settings when starting the device. **/
struct ADS1115settings {

34

/**
* I2C bus used (99% always set to one) **/
int i2c_bus = 1;

/**
* I2C address of the ads1115
**/
uint8_t address = DEFAULT_ADS1115_ADDRESS; };

/**
* Starts the data acquisition in the background and the * callback is called with new samples.
* \param settings A struct with the settings.
**/
void start(ADS1115settings settings = ADS1115settings() );

If a setter sets large buffers then it’s highly recommended to allocate the memory in the constructor of the class and then call the setter by reference while running. Use array types which convey their length, for example std::array or a standard const array which implicitly carries their length.

Constant sampling rate output (audio, . . . ) There are many applications where the output device has a fixed sampling rate, for example digital to analogue converters. In this case the C++ driver class will again have a blocking write-loop periodically reading a buffer populated by the setter, which is ideally always ahead of time. You need to decide what happens if no fresh data has arrived, for example interpolating the output or putting it on hold. Of course you can also implement a callback by the audio write-loop to request samples but ultimately the conflict between audio arriving and being dispatched needs to be resolved.

## 6.1 Conclusion

Setters are simply methods which transmit an event back to the physical device. Setters should, as callbacks, always hide the low level complexity of the hardware device and receive normalised or physical units.

35

# Appendix A

# License

This work is licensed under the Creative Commons Attribution-ShareAlike 4.0 International License. To view a copy of this license, visit http://creativecommons.org/licenses/by-sa/4.0/ (http://creativecommons.org/licenses/by-sa/4.0/) or send a letter to Creative Commons, PO Box 1866, Mountain View, CA.

36

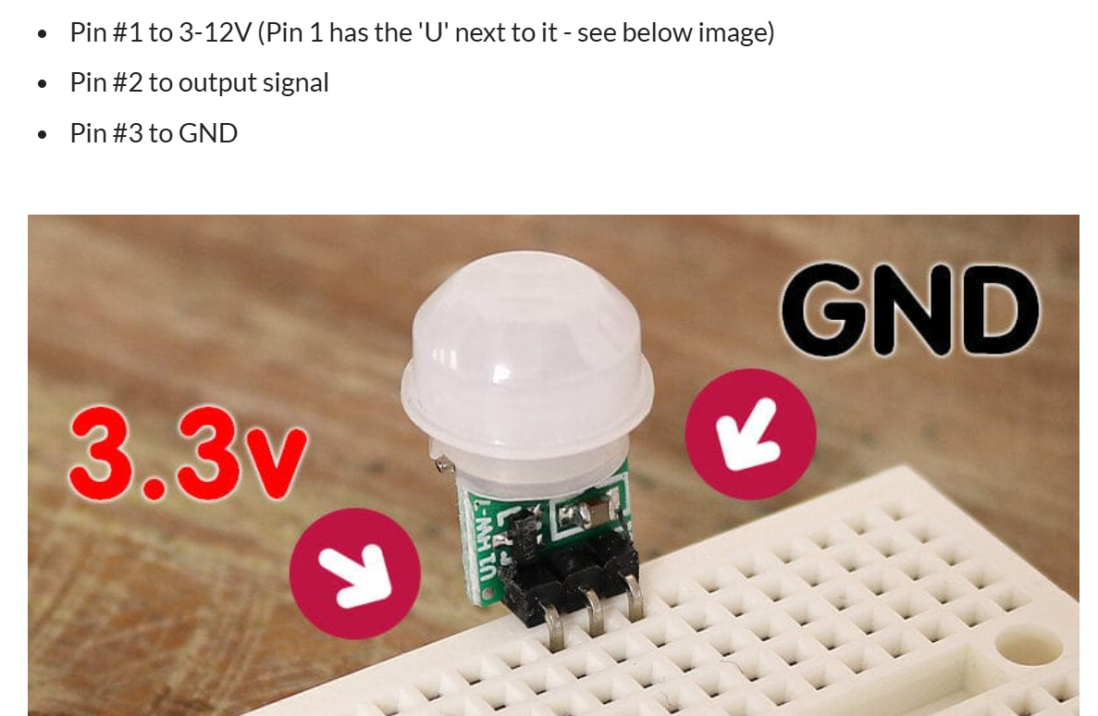
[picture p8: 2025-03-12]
Project Details/PIR Pinout.png

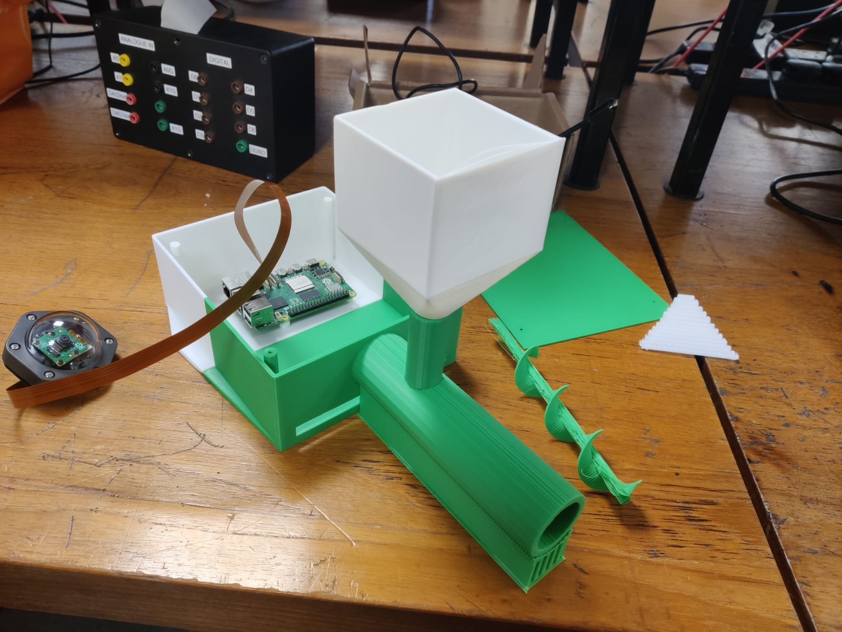
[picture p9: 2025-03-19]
images/Project Image.jpg

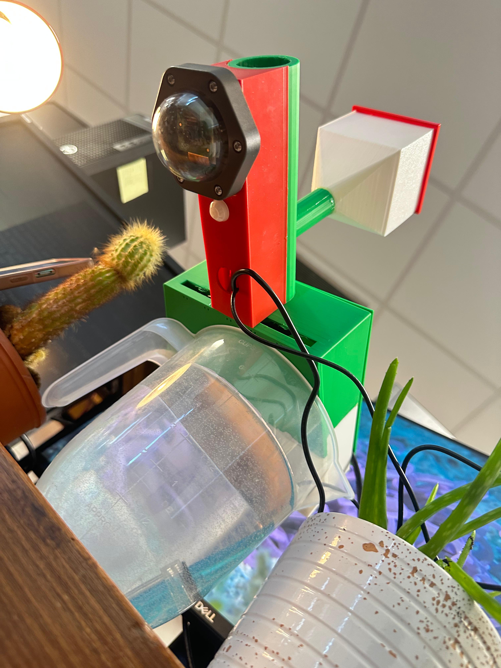
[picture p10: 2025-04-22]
images/Bottom_Right.jpg

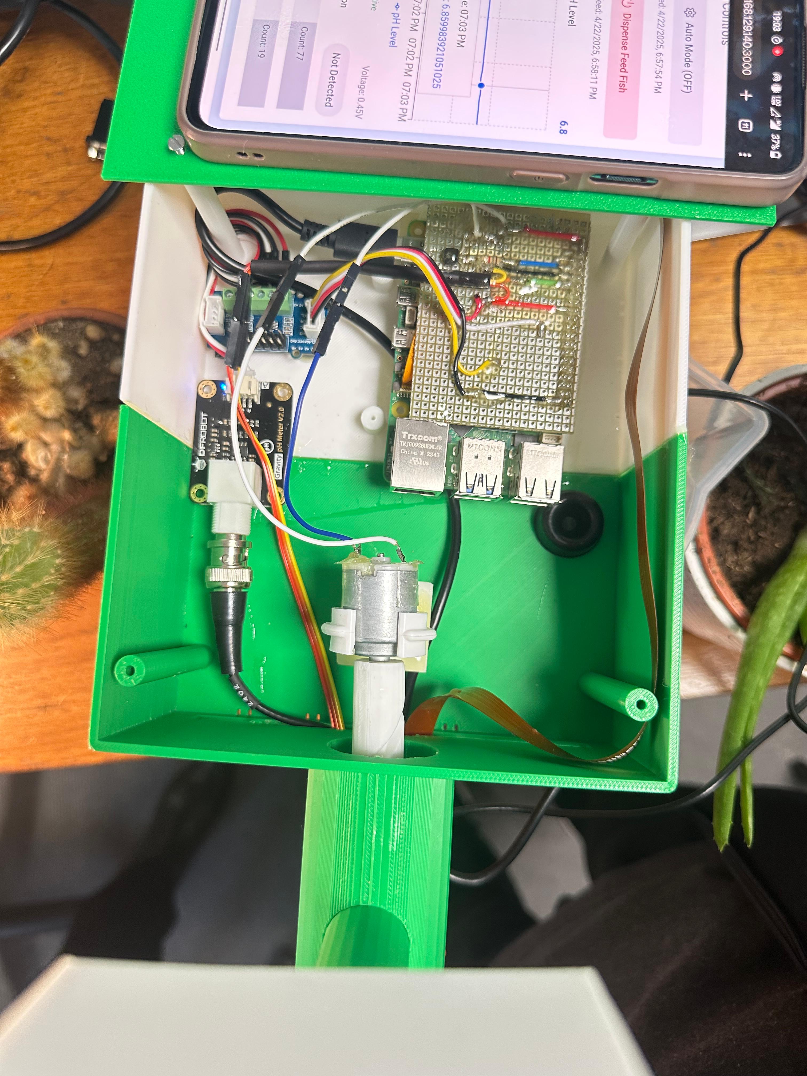
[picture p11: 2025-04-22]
images/Top.jpg

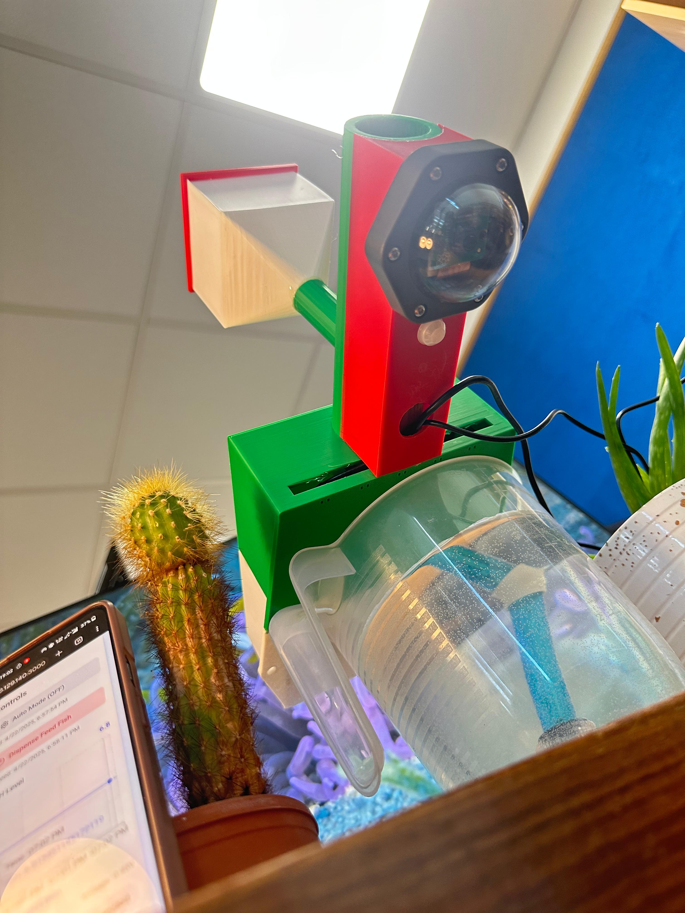
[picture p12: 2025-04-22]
images/Bottom_Left.jpg

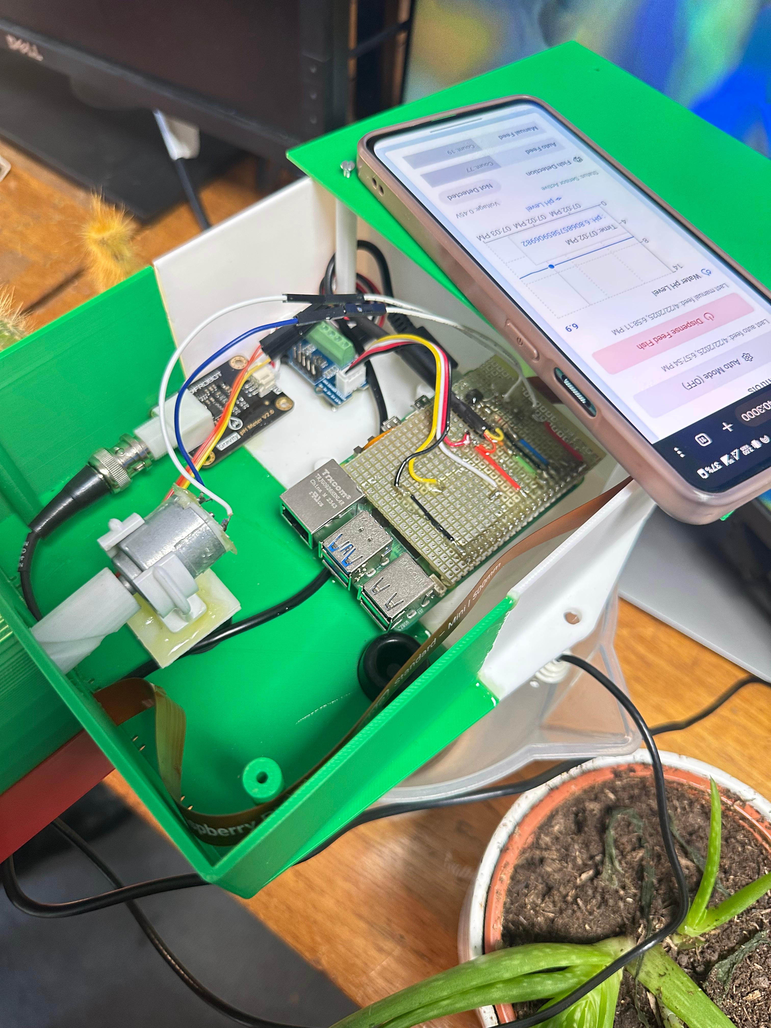
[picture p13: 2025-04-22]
images/Top_Right.jpg

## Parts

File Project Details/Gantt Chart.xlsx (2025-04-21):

S.No | Phase | Task | Details | Start Date | End Date | Assigned To | Status | Resource Needs | Hardware Involved | Software Involved | Tools Required | Testing Required | Documentation Needed | Peer Review Status | Testing Completed | Approved By Team | Submitted to GitHub | Final Review Status
1 | Project Initialization | Define project scope & objectives | Clarify Aqua Feed Pi's real-world problem, realtime necessity, and outcomes | 2025-02-01 | 2025-02-02 | All | Done | None | None | None | None | No | Yes | Done | Not Required | Yes | Submitted | Done
2 | Project Initialization | Submit final form on Moodle | Upload member list + GitHub link | 2025-02-02 | 2025-02-03 | Atharv & Gagan | Done | GitHub | None | None | None | No | Yes | Done | Not Required | Yes | Submitted | Done
3 | Project Initialization | GitHub repo setup | Create README, license, main branches, and placeholder files | 2025-02-04 | 2025-02-06 | Gagan & Syafiq | Done | GitHub | None | None | None | No | Yes | Done | Not Required | Yes | Submitted | Done
4 | Project Initialization | Pitch slides creation | Design 2 slides covering concept, hardware, realtime value | 2025-04-04 | 2025-04-05 | Gagan & Atharv | Done | Microsoft PPT | None | None | Microsoft PPT | No | Yes | Done | Not Required | Yes | Submitted | Done
5 | Project Initialization | Initial pitch delivery | Present project and receive feedback | 2025-02-05 | 2025-02-12 | All | Done | Microsoft PPT | None | None | Microsoft PPT | No | Yes | Done | Not Required | Yes | Submitted | Done
6 | Design & Planning | Define data flow diagram | Visualize the flow of sensor data to motor control and UI | 2025-02-06 | 2025-02-15 | Rahil & Syafiq | Done | Canva | None | Canva | Canva | No | Yes | Done | Not Required | Yes | Submitted | Done
7 | Design & Planning | Hardware specification | List and finalize required components (servo, sensors, Pi) | 2025-02-15 | 2025-02-25 | Wen Jun & Atharv | Done | None | None | None | None | No | Yes | Done | Not Required | Yes | Submitted | Done
8 | Design & Planning | Hardware procurement | Order parts using £45 budget and technician access | 2025-02-26 | 2025-03-03 | Wen Jun & Atharv | Done | None | None | None | None | No | Yes | Done | Not Required | Yes | Submitted | Done
9 | Design & Planning | Class design (UML-style) | Map out object-oriented structure using SOLID principles | 2025-03-05 | 2025-03-09 | Rahil & Wen Jun | Done | None | None | None | None | No | Yes | Done | Not Required | Yes | Submitted | Done
10 | Design & Planning | Create pin mapping and wiring plan | Document GPIO pin usage and safety checks | 2025-03-03 | 2025-03-04 | Rahil & Syafiq | Done | None | None | None | None | No | Yes | Done | Not Required | Yes | Submitted | Done
11 | Development Phase 1 | 3D Design of the components | Create a 3D model in Sketch up | 2025-02-16 | 2025-02-26 | Gagan & Syafiq | Done | Sketchup | None | Sketchup | Sketchup | No | Yes | Done | Not Required | Yes | Submitted | Done
12 | Development Phase 1 | 3D Printing of the components | 3D printing of the model in the University Lab | 2025-03-05 | 2025-03-08 | Gagan & Syafiq | Done | Sketchup | None | Sketchup | Sketchup | No | Yes | Done | Not Required | Yes | Submitted | Done
13 | Development Phase 1 | Sensor integration | Interface temp and water level sensors to Pi, validate data readout | 2025-03-09 | 2025-03-12 | Rahil & Atharv | Done | Rasaspberry Pi | Rasaspberry Pi | C++ | Rasaspberry Pi, C++ | Yes | Yes | Done | Done | Yes | Submitted | Done
14 | Development Phase 1 | Motor control setup | Use PWM via GPIO to control servo for feeding | 2025-03-10 | 2025-03-15 | Wen Jun & Atharv | Done | Servo Motor, Rasaspberry Pi | Servo Motor, Rasaspberry Pi | C++ | Servo Motor, Rasaspberry Pi, C++ | Yes | Yes | Done | Done | Yes | Submitted | Done
15 | Development Phase 1 | UI control setup | Basic GUI or command interface for feed timing/parameters | 2025-03-13 | 2025-03-16 | Rahil & Atharv | Done | Rasaspberry Pi | Rasaspberry Pi | C++ | Rasaspberry Pi, C++ | Yes | Yes | Done | Done | Yes | Submitted | Done
16 | Development Phase 1 | Callback/event framework | Implement threaded or signal-driven logic for events | 2025-03-16 | 2025-03-19 | Rahil | Done | C++ | None | C++ | C++ | Yes | Yes | Done | Done | Yes | Submitted | Done
17 | Development Phase 1 | Latency & fault handling | Test & optimize sensor-to-response latency, handle anomalies | 2025-03-19 | 2025-03-24 | Rahil | Done | Rasaspberry Pi | Rasaspberry Pi | C++ | Rasaspberry Pi, C++ | Yes | Yes | Done | Done | Yes | Submitted | Done
18 | Development Phase 1 | Sensor calibration | Calibrate temperature and water level sensors for accuracy | 2025-03-19 | 2025-03-20 | Atharv & Rahil | Done | Rasaspberry Pi, Sensors | Rasaspberry Pi, Sensors | C++ | Rasaspberry Pi, Sensors,C++ | Yes | Yes | Done | Done | Yes | Submitted | Done
19 | Development Phase 2 | Create sensor abstraction class | Design modular class for sensor readouts | 2025-03-18 | 2025-03-19 | Rahil | Done | C++ | None | C++ | C++ | Yes | Yes | Done | Done | Yes | Submitted | Done
20 | Development Phase 2 | Basic signal plotting | Plot real-time signals on screen or log to file | 2025-03-19 | 2025-03-20 | Gagan & Wen Jun | Done | C++ | None | C++ | C++ | Yes | Yes | Done | Done | Yes | Submitted | Done
21 | Development Phase 2 | Implement alert system | Notify if thresholds are crossed (e.g., low water) | 2025-03-20 | 2025-03-21 | Rahil & Wen Jun | Done | C++ | None | C++ | C++ | Yes | Yes | Done | Done | Yes | Submitted | Done
22 | Development Phase 2 | UI event binding | Bind UI controls to logic and backend state | 2025-03-21 | 2025-03-22 | Rahil | Done | C++ | None | C++ | C++ | Yes | Yes | Done | Done | Yes | Submitted | Done
23 | Development Phase 2 | Non-blocking threading | Use threads/signals to avoid blocking in loops | 2025-03-21 | 2025-03-23 | Rahil & Wen Jun | Done | C++ | None | C++ | C++ | Yes | Yes | Done | Done | Yes | Submitted | Done
24 | Development Phase 2 | Exception handling routines | Add safety checks and exception logging | 2025-03-23 | 2025-03-25 | Rahil & Wen Jun | Done | C++ | None | C++ | C++ | Yes | Yes | Done | Done | Yes | Submitted | Done
25 | Development Phase 2 | Webpage for User Interface | Creating webpage and integrate UI with backend | 2025-03-26 | 2025-03-28 | Gagan & Syafiq | Done | C++, JSON, Github | Raspberry Pi, Sensors, Motor | C++, JSON, Github | C++, JSON, Github | Yes | Yes | Done | Done | Yes | Submitted | Done
26 | Development Phase 2 | Create user features | Debugging backend to integrate with UI, add user features (e.g., pH level plot) | 2025-03-27 | 2025-03-29 | Gagan & Syafiq | Done | C++, JSON, Github | Raspberry Pi, Sensors, Motor | C++, JSON, Github | C++, JSON, Github | Yes | Yes | Done | Done | Yes | Submitted | Done
27 | Testing & Version Control | Set up Git strategy | Define commit discipline, use branches & issues | 2025-04-24 | 2025-04-24 | Rahil & Wen Jun | Done | C++ | None | C++ | C++ | No | Yes | Done | Not Required | Yes | Submitted | Done
28 | Testing & Version Control | Unit & integration testing | Test each module independently + integrated run | 2025-04-25 | 2025-04-26 | Rahil & Wen Jun | Done | AquaFeeder, Rasaspberry Pi | AquaFeeder, Rasaspberry Pi | C++ | AquaFeeder, Rasaspberry Pi, C++ | Yes | Yes | Done | Done | Yes | Submitted | Done
29 | Testing & Version Control | Create test cases for each module | Unit test for sensor, feeder, and UI modules | 2025-03-28 | 2025-03-30 | Atharv & Rahil | Done | AquaFeeder, Rasaspberry Pi | AquaFeeder, Rasaspberry Pi | C++ | AquaFeeder, Rasaspberry Pi, C++ | Yes | Yes | Done | Done | Yes | Submitted | Done
30 | Testing & Version Control | Run latency tests | Measure sensor-to-actuation time under load | 2025-03-28 | 2025-03-30 | Rahil & Wen Jun | Done | C++ | C++ | C++ | C++ | Yes | Yes | Done | Done | Yes | Submitted | Done
31 | Documentation & PR | Write GitHub documentation | README, usage, diagrams, architecture, hardware setup | 2025-03-26 | 2025-03-28 | Gagan & Syafiq | Done | GitHub | None | None | GitHub | No | Yes | Done | Not Required | Yes | Submitted | Done
32 | Documentation & PR | Create visual content | Demo, record GIF, upload to repo | 2025-03-25 | 2025-03-27 | Gagan & Syafiq | Done | Camera | None | None | Camera | No | Yes | Done | Not Required | Yes | Submitted | Done
33 | Documentation & PR | Social media & promotion | Announce project on LinkedIn & Instagram | 2025-03-02 | 2025-03-03 | Atharv & Gagan | Done | Instagram & LinkedIn | None | None | Instagram & LinkedIn | No | Yes | Done | Not Required | Yes | Submitted | Done
34 | Finalization | Create GitHub release | Package, tag, and publish final release | 2025-04-04 | 2025-04-10 | All | Done | GitHub | None | None | GitHub | No | Yes | Done | Not Required | Yes | Submitted | Done
35 | Finalization | Freeze codebase | Stop feature development, perform code cleanup and bug fixing | 2025-04-12 | 2025-04-15 | Atharv & Wen Jun | Done | C++ | None | None | C++ | Yes | Yes | Done | Done | Yes | Submitted | Done
36 | Finalization | Final testing | Comprehensive system testing and final bug resolution | 2025-04-13 | 2025-04-17 | Gagan & Wen Jun | Done | AquaMatic | AquaMatic | C++ | AquaMatic, C++ | Yes | Yes | Done | Done | Yes | Submitted | Done
37 | Finalization | Prepare final GitHub release | Create and tag a stable release on GitHub | 2025-04-17 | 2025-04-18 | Rahil & Wen Jun | Done | GitHub | None | None | GitHub | No | Yes | Done | Not Required | Yes | Submitted | Done
38 | Finalization | Update final documentation | Finalize README, diagrams, and how-to sections | 2025-04-17 | 2025-04-18 | Gagan & Wen Jun | Done | GitHub | None | None | GitHub | No | Yes | Done | Not Required | Yes | Submitted | Done
39 | Finalization | Upload video demo | Create, edit, and upload a walkthrough demo | 2025-04-17 | 2025-04-19 | Atharv & Gagan | Done | GitHub | None | None | GitHub | No | Yes | Done | Not Required | Yes | Submitted | Done
40 | Finalization | Peer review & internal feedback | Review by all team members and adjustments based on feedback | 2025-04-18 | 2025-04-20 | All | Done | GitHub | None | None | GitHub | No | Yes | Done | Not Required | Yes | Submitted | Done
41 | Finalization | Submit final GitHub link to Moodle | Official submission of final deliverables | 2025-04-20 | 2025-04-21 | All | Done | GitHub | None | None | GitHub | No | Yes | Done | Not Required | Yes | Submitted | Done
42 | Finalization | Backup & archive | Save a copy of code, documentation, and assets | 2025-04-20 | 2025-04-21 | All | Done | None | None | None | None | No | Yes | Done | Not Required | Yes | Submitted | Done
43 | Finalization | Team retrospective | Discuss project outcomes, lessons learned, improvements | 2025-04-21 | 2025-04-23 | All | Pending | None | None | None | None | No | Yes | Done | Not Required | Yes | Submitted | Done

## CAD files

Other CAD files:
3D_files/design3dmm.skp

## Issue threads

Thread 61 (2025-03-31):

pH Sensor :- Memory api to Live

Deshad, 2025-03-31:
The front end shows the pH and related voltage but doesn't update.

Closed 2025-03-31.

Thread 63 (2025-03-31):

Camera Feed

Deshad, 2025-03-31:
Camera is being used to detect the fish using openCV, but we can't do live stream from the camera as it can't be used to two things at the same time, we need to find a way to use it in API and Live stream at front end simultaneously.

Deshad, 2025-04-01:
To handle both the API and the streaming concurrently, you can use multi-threading or multi-processing. Each task can run in its own thread or process to ensure they don't block each other.

Option A: Multi-threading with FastCGI and Streaming
You can use Python's threading module to run both the FastCGI server (handling API requests) and the camera stream concurrently. This works well if you need to perform basic tasks like capturing frames and serving them through the API.

Closed 2025-04-21.

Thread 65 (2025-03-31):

Fix Auto Mode(ON)

Deshad, 2025-03-31:
The Auto Mode button on the webpage should turn off the automatic fish feeding system. It should bypass the feeding system and the system should only work when the user presses the Dispense Feed fish Button.

Deshad, 2025-04-01:
The auto mode needs to kill the motor,
the auto mode on uses sensor.fishDetected. we need to create a function that does opposite of that function.

Closed 2025-04-02.

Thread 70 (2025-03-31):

Fix Spiral feeder

Deshad, 2025-03-31:
The spiral Feeder needs to be fixed.

Deshad, 2025-04-01:
The motor needs to be fixed again and see if the red spiral works rather than the white one, the white spiral dangles a lot when it rotates as motor is not fixed and due to its inertia.

Closed 2025-04-19.

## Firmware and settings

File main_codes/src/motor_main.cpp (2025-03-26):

#include "motor.h"
#include <iostream>
#include <string>

int main(int argc, char* argv[]) {
    int motorPin = 4;  // Default GPIO pin
    
    // Allow pin override via command line
    if (argc > 1) {
        try {
            motorPin = std::stoi(argv[1]);
        } catch (const std::exception& e) {
            std::cerr << "Invalid pin number: " << argv[1] << std::endl;
            return 1;
        }
    }
    
    std::cout << "Motor Test Program" << std::endl;
    std::cout << "==================" << std::endl;
    std::cout << "Using GPIO pin: " << motorPin << std::endl;
    
    try {
        // Create motor controller
        Motor motor(motorPin);
        
        if (!motor.isInitialized()) {
            std::cerr << "Failed to initialize motor on pin " << motorPin << std::endl;
            return 1;
        }
        
        // Run motor sequence
        std::cout << "\nMotor Test Sequence:" << std::endl;
        std::cout << "-------------------" << std::endl;
        
        std::cout << "100% duty cycle (Full speed) for 2 seconds" << std::endl;
        motor.run(100, 10, 2000);
        
        std::cout << "50% duty cycle for 2 seconds" << std::endl;
        motor.run(50, 10, 2000);
        
        std::cout << "25% duty cycle for 2 seconds" << std::endl;
        motor.run(25, 10, 2000);
        
        std::cout << "0% duty cycle (OFF) for 2 seconds" << std::endl;
        motor.run(0, 10, 2000);
        
        std::cout << "Ramp up sequence..." << std::endl;
        for (int i = 0; i <= 100; i += 10) {
            std::cout << i << "% duty cycle" << std::endl;
            motor.run(100, 10, 500);
        }
        
        
        
        std::cout << "Stopping motor..." << std::endl;
        motor.stop();
        
        std::cout << "\nTest complete!" << std::endl;
        
    } catch (const std::exception& e) {
        std::cerr << "Error: " << e.what() << std::endl;
        return 1;
    }
    
    return 0;
}

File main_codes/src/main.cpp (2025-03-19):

#include "fish_monitoring_system.h"
#include <iostream>

int main() {
    try {
        // Create and start system
        FishMonitoringSystem system;
        system.start();
        
        std::cout << "System is running. Press Enter to exit." << std::endl;
        std::cin.get();
        
        system.stop();
        std::cout << "System shut down. Goodbye!" << std::endl;
        
    } catch (const std::exception& e) {
        std::cerr << "Error: " << e.what() << std::endl;
        return 1;
    }
    
    return 0;
}

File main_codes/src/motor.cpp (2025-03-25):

#include "motor.h"
#include <iostream>
#include <chrono>
#include <thread>

Motor::Motor(int motorPin, const char* chipPath) 
    : m_motorPin(motorPin), 
      m_chip(nullptr), 
      m_motorLine(nullptr), 
      m_gpioInitialized(false) {
    
    // Initialize GPIO
    m_chip = gpiod_chip_open(chipPath);
    if (!m_chip) {
        std::cerr << "Failed to open GPIO chip for motor control!" << std::endl;
        return;
    }
    
    m_motorLine = gpiod_chip_get_line(m_chip, m_motorPin);
    if (!m_motorLine) {
        std::cerr << "Failed to get GPIO line for motor control!" << std::endl;
        gpiod_chip_close(m_chip);
        m_chip = nullptr;
        return;
    }
    
    if (gpiod_line_request_output(m_motorLine, "motor_control", 0) < 0) {
        std::cerr << "Failed to request GPIO line as output for motor control!" << std::endl;
        gpiod_chip_close(m_chip);
        m_chip = nullptr;
        m_motorLine = nullptr;
        return;
    }
    
    m_gpioInitialized = true;
    std::cout << "Motor initialized on GPIO pin " << m_motorPin << std::endl;
}

Motor::~Motor() {
    stop();
    
    if (m_motorLine) {
        gpiod_line_release(m_motorLine);
    }
    
    if (m_chip) {
        gpiod_chip_close(m_chip);
    }
}

bool Motor::run(int dutyCycle, int periodMs, int durationMs) {
    if (!m_gpioInitialized || !m_motorLine) {
        std::cerr << "Cannot run motor: GPIO not initialized" << std::endl;
        return false;
    }
    
    // Clamp duty cycle to 0-100 range
    dutyCycle = std::max(0, std::min(100, dutyCycle));
    
    std::cout << "Running motor at " << dutyCycle << "% duty cycle for " 
              << durationMs << "ms..." << std::endl;
    
    auto startTime = std::chrono::steady_clock::now();
    
    while (std::chrono::steady_clock::now() - startTime < std::chrono::milliseconds(durationMs)) {
        if (dutyCycle > 0) {
            // Turn ON the motor (HIGH)
            gpiod_line_set_value(m_motorLine, 1);
            std::this_thread::sleep_for(std::chrono::milliseconds(dutyCycle * periodMs / 100));
        }
        
        if (dutyCycle < 100) {
            // Turn OFF the motor (LOW)
            gpiod_line_set_value(m_motorLine, 0);
            std::this_thread::sleep_for(std::chrono::milliseconds((100 - dutyCycle) * periodMs / 100));
        }
    }
    
    return true;
}

void Motor::stop() {
    if (m_gpioInitialized && m_motorLine) {
        gpiod_line_set_value(m_motorLine, 0);
        std::cout << "Motor stopped" << std::endl;
    }
}

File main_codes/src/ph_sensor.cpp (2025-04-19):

#include "ph_sensor.h"
#include <iostream>
#include <fcntl.h>
#include <unistd.h>
#include <sys/ioctl.h>
#include <linux/i2c-dev.h>
#include <i2c/smbus.h>
#include <chrono>
#include <thread>

// ADS1115 settings
static const char *I2C_DEVICE = "/dev/i2c-1";
static const uint8_t I2C_ADDR = 0x48;
#define CONFIG_REG 0x01
#define CONVERSION_REG 0x00

// Updated calibration constants
static const float V_REF = 2.048; // PGA ±2.048V
static const float SLOPE = -12.5; //  slope
static const float OFFSET = 12.5; //  offset

PHSensor::PHSensor() : m_fd(-1) {
}

PHSensor::~PHSensor() {
    cleanup();
}

void PHSensor::registerCallback(PHSensorCallbackInterface* callback) {
    m_callbackInterfaces.push_back(callback);
}

bool PHSensor::initialize() {
    // Close previous descriptor if open
    if (m_fd >= 0) {
        close(m_fd);
        m_fd = -1;
    }
    
    m_fd = open(I2C_DEVICE, O_RDWR);
    if (m_fd < 0) {
        std::cerr << "Failed to open I2C device" << std::endl;
        return false;
    }
    
    if (ioctl(m_fd, I2C_SLAVE, I2C_ADDR) < 0) {
        std::cerr << "Failed to set I2C address" << std::endl;
        close(m_fd);
        m_fd = -1;
        return false;
    }
    
    std::cout << "pH Sensor initialized successfully" << std::endl;
    return true;
}

void PHSensor::cleanup() {
    if (m_fd >= 0) {
        close(m_fd);
        m_fd = -1;
        std::cout << "pH Sensor resources cleaned up" << std::endl;
    }
}

float PHSensor::readPH() {
    // Making sure the sensor is initialized
    if (!isInitialized()) {
        std::cout << "Sensor not initialized, initializing now..." << std::endl;
        if (!initialize()) {
            std::cerr << "Cannot read pH: Sensor initialization failed" << std::endl;
            return -1.0f;
        }
    }
    
    // Read raw ADC value 
    int16_t adcValue = readADC();
    if (adcValue < 0) {
        std::cerr << "Failed to read ADC" << std::endl;
        return -1.0f;
    }
    
    // Convert to voltage
    float voltage = adcToVoltage(adcValue);
    
    // Convert to pH
    float pH = voltageToPH(voltage);
    
    // Notify callbacks
    notifyCallbacks(pH, voltage, adcValue);
    
    // Print the same output 
    std::cout << "Raw ADC: " << adcValue << " | Voltage: " << voltage
              << "V | pH: " << pH << std::endl;
    
    return pH;
}

int16_t PHSensor::readADC() {
    uint16_t config = (1 << 15) | // Start conversion
                      (0 << 12) | // A0 single-ended (MUX = 000)
                      (2 << 9)  | // ±2.048V gain (PGA = 010)
                      (0 << 8)  | // Single-shot
                      (4 << 5)  | // 128 SPS
                      (0 << 4)  | // Comparator off
                      (3);        // Disable comparator
    
    uint8_t config_bytes[3] = {
        CONFIG_REG,
        static_cast<uint8_t>((config >> 8) & 0xFF),
        static_cast<uint8_t>(config & 0xFF)
    };
    
    if (write(m_fd, config_bytes, 3) != 3) {
        std::cerr << "Failed to write config" << std::endl;
        return -1;
    }
    
    std::this_thread::sleep_for(std::chrono::milliseconds(10));
    
    // Read back config 
    uint8_t reg = CONFIG_REG;
    if (write(m_fd, &reg, 1) != 1) {
        std::cerr << "Failed to set config register for read" << std::endl;
        return -1;
    }
    
    uint8_t config_read[2];
    if (read(m_fd, config_read, 2) != 2) {
        std::cerr << "Failed to read config" << std::endl;
        return -1;
    }
    
    uint16_t config_check = (config_read[0] << 8) | config_read[1];
    std::cout << "Config Register: 0x" << std::hex << config_check << std::dec << std::endl;
    
    // Read conversion register
    reg = CONVERSION_REG;
    if (write(m_fd, &reg, 1) != 1) {
        std::cerr << "Failed to set conversion register" << std::endl;
        return -1;
    }
    
    uint8_t data[2];
    if (read(m_fd, data, 2) != 2) {
        std::cerr << "Failed to read conversion" << std::endl;
        return -1;
    }
    
    // Combine 16-bit result (big-endian)
    return (data[0] << 8) | data[1];
}

float PHSensor::adcToVoltage(int16_t adcValue) {
    // Using the updated calculation with 2.048V reference
    return (adcValue * V_REF) / 32767.0; // 0-32767 maps to 0-2.048V
}

float PHSensor::voltageToPH(float voltage) {
    return SLOPE * voltage + OFFSET;
}

void PHSensor::notifyCallbacks(float pH, float voltage, int16_t adcValue) {
    for (auto& callback : m_callbackInterfaces) {
        callback->onPHSample(pH, voltage, adcValue);
    }
}

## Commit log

2025-03-05 Add motor control API implementation
2025-03-12 Add basic camera capture functionality using libcamera-still
2025-03-19 Create Sensors
2025-03-19 Create Sensors Detail
2025-03-19 Updated To Event driven with Threads and Callback
2025-03-19 Missed Some files in Commit #17
    [feeder.cpp, fish_monitoring_system.cpp]
2025-03-24 Motor Integration #30
2025-03-24 Updating to try to Detect 3D Printed Fish
2025-03-24 Faster Response Time From Camera
2025-03-25 PH Sensor Integration #36
2025-03-26 Move camera_detection contents directly into Main folder
2025-04-01 cleaning files
    [design3dmm.skp]
2025-04-19 Update camera.h
    Comments
